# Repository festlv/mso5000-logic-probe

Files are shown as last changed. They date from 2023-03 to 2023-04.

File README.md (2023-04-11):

# MSO5000 logic analyzer probe

This project aims to be a somewhat lower performance but significantly cheaper alternative to Rigol's PLA2216 
logic analyzer probe for MSO5000-series oscilloscopes.

The project is based on the design published by Gandalf_Sr on [EEVBlog forum](https://www.eevblog.com/forum/testgear/ms05000-budget-logic-analyzer-probe-set-design/), 
with the most notable difference being that it should allow input signal threshold selection from the oscilloscope.

The project consists of two PCBs: 

* __connector-pcb__ which plugs into oscilloscope,
* 2x __probe-pcb__'s which connect to the aforementioned PCB via 24-pin IDC cables.

As the original design, it aims to support ~1-5V logic levels up to 100MHz. The probe PCBs can be built with 
two different TI level-shifters:

* SN74AXC8T245 with specified input range of 0.65-3.6V (4.2V abs. max).
* SN74**L**XC8T245 with specified input range of 1.1-5.5V (6.2V abs. max).

Do note that the propagation delay for lower input voltages can limit the observable signal's bandwidth!

## Current status

Revision 0 of both PCBAs has been assembled and passed basic function checks. The only required change was that series resistor
for ProbeDet signal was apparently too high (10K->100R).

Do keep in mind that the threshold level set in scope is not executed faitfhully- it's essentially amplified with a gain of 16.8
and provided as Vcc for SN74AXC8T245. See the datasheet of SN74AXC8T245 and connector-pcb/threshold-vcc-gain-calc.ods spreadsheet for details.

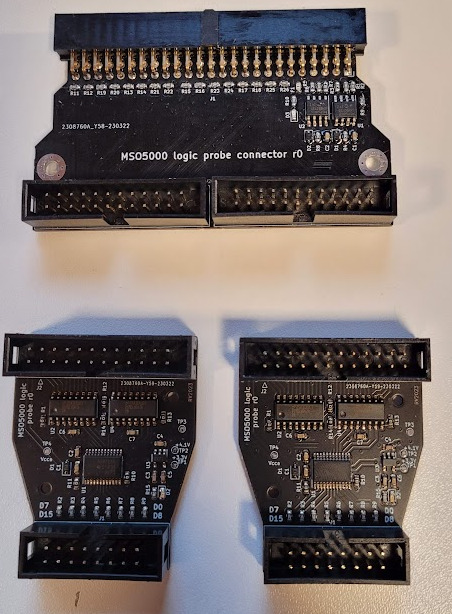
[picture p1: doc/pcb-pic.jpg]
pcb pics


## Connector PCB

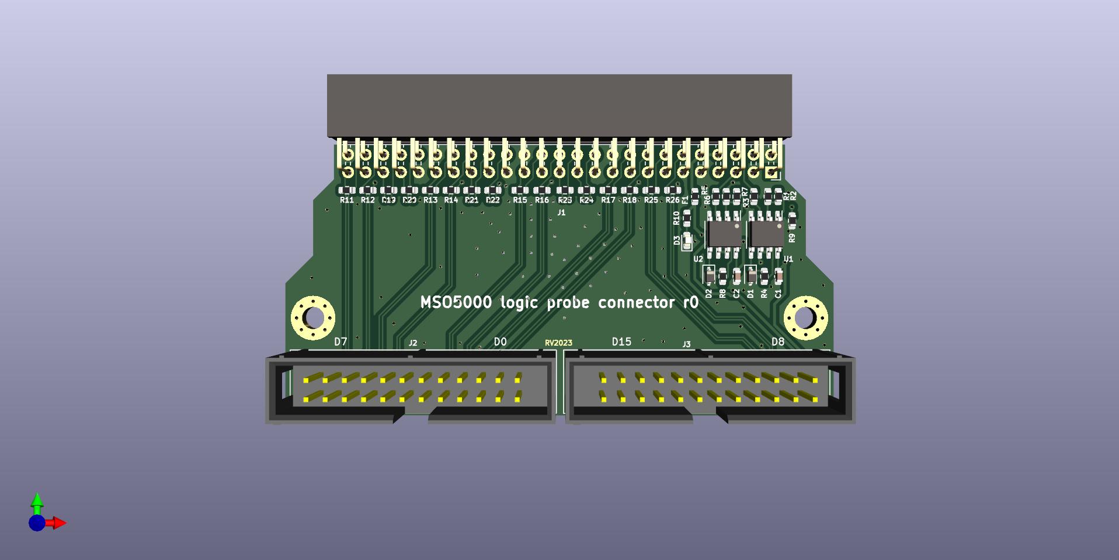
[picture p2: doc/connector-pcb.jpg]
connector pcb


## Probe PCB

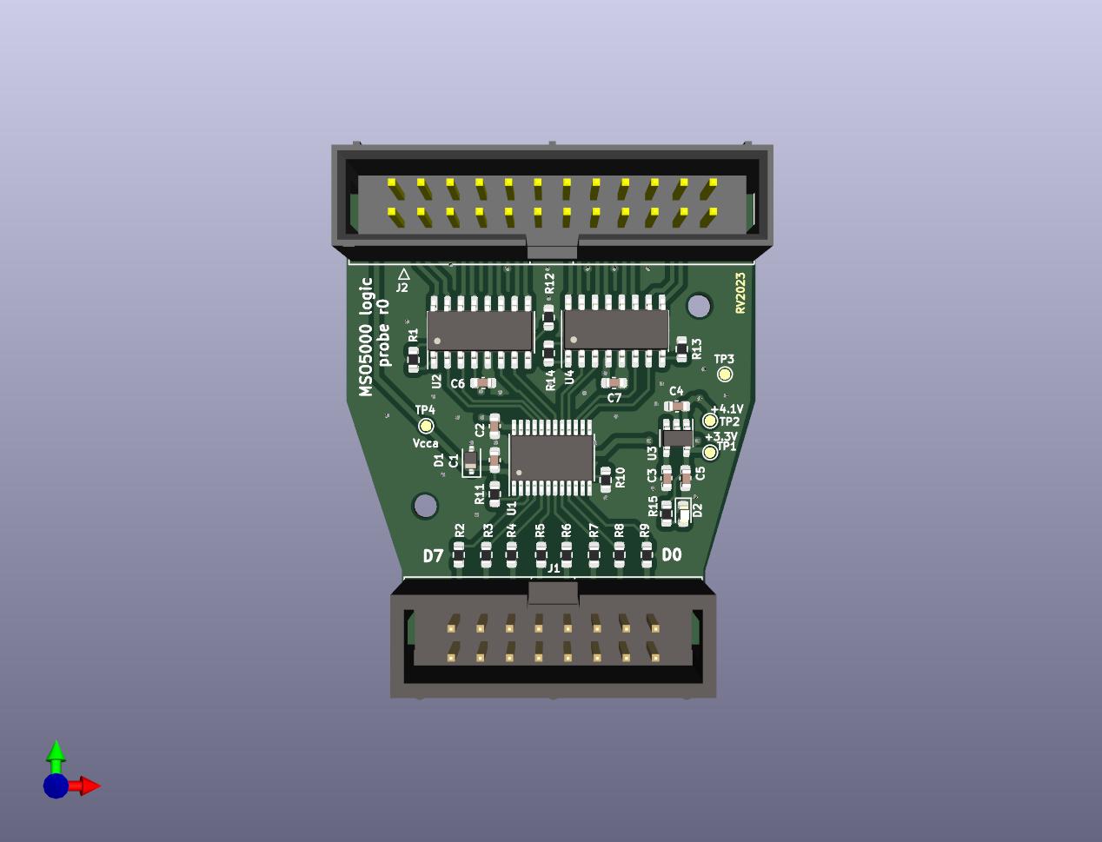
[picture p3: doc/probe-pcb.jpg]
probe pcb


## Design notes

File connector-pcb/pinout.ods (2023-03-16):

ProbeDet | GND | ProbeDet
GND | -2.5Vin | GND
Vref_8-15 | Vref_0-7 | GND
+2.5Vin | +4Vin | -2.5Vin
GND | +4vin | Vref_8-15
GND | D8_N | Vref_0-7
D8_P | D9_p | +2.5Vin
D9_N | D0_N | +4Vin
D0_P | D1_P | GND
D1_N | GND | +4vin
GND | D10_N | GND
D10_P | D11_N | D8_N
DI1_P | D2_N | D8_P
D2_P | D3_P | D9_p
D3_N | GND | D9_N
GND | D12_N | D0_N
D12_P | D13_P | D0_P
D13_N | D4_N | D1_P
D4_P | D5_P | D1_N
D5_N | GND | GND
GND | D14_P | GND
D14_N | D15_P | D10_N
D15_N | D6_N | D10_P
D6_P | D7_P | D11_N
D7_N | GND | DI1_P
 |  | D2_N
 |  | D2_P
 |  | D3_P
 |  | D3_N
 |  | GND
 |  | GND
 |  | D12_N
 |  | D12_P
 |  | D13_P
 |  | D13_N
 |  | D4_N
 |  | D4_P
 |  | D5_P
 |  | D5_N
 |  | GND
 |  | GND
 |  | D14_P
 |  | D14_N
 |  | D15_P
 |  | D15_N
 |  | D6_N
 |  | D6_P
 |  | D7_P
 |  | D7_N
 |  | GND

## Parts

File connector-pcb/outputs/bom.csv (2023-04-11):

Source: | /home/reinis/personal/mso5000-logic/connector-pcb/connector-pcb.kicad_sch
Date: | Tue 11 Apr 2023 07:54:40 PM EEST
Tool: | Eeschema 7.0.1
Generator: | /usr/share/kicad/plugins/bom_csv_grouped_by_value.py
Component Count: | 37
Collated Components:
Item | Qty | Reference(s) | Value | LibPart | Footprint | Datasheet | DNP | LCSC# | MPN | Manufacturer
1 | 2 | C1, C2 | 0.1uF | Device:C_Small | Capacitor_SMD:C_0603_1608Metric | ~ |  | C1591 | CL10B104KB8NNNC | Samsung Electro-Mechanics
2 | 2 | D1, D2 | 3.9V 5% | Device:D_Zener_Small | Diode_SMD:D_SOD-323 | ~ |  | C5359777 | MM3Z3V9 | Fosan
3 | 1 | D3 | LED_GRN | Device:LED_Small | LED_SMD:LED_0603_1608Metric | ~ |  | C965805 | XL-1608SYGC-06 | XINGLIGHT
4 | 1 | F1 | 0.5A | Device:Polyfuse_Small | Fuse:Fuse_0603_1608Metric | ~ |  | C210356 | MF-FSMF020X-2 | BOURNS
5 | 1 | J1 | MSO5000_LA | mso5000:MSO5000_LA | Connector_PinSocket_2.54mm:PinSocket_2x25_P2.54mm_Horizontal | ~ |  |  | SFH11-PBPC-D25-RA-BK | Sullins Connector Solutions
6 | 2 | J2, J3 | IDC_HEADER_2x12 | Connector_Generic:Conn_02x12_Odd_Even | idc:IDC-Header_2x12_P2.54mm_Vertical | ~ |  | C132440 | B-3000S24P-0110 | Ckmtw(Shenzhen Cankemeng)
7 | 3 | R1, R6, R10 | 1K | Device:R_Small | Resistor_SMD:R_0603_1608Metric | ~ |  | C22548 | RC0603FR-071KL | YAGEO
8 | 2 | R2, R7 | 15K8 | Device:R_Small | Resistor_SMD:R_0603_1608Metric | ~ |  | C155689 | RC0603FR-0715K8L | YAGEO
9 | 4 | R3, R4, R5, R8 | 10K | Device:R_Small | Resistor_SMD:R_0603_1608Metric | ~ |  | C98220 | RC0603FR-0710KL | YAGEO
10 | 17 | R9, R11, R12, R13, R14, R15, R16, R17, R18, R19, R20, R21, R22, R23, R24, R25, R26 | 100R | Device:R_Small | Resistor_SMD:R_0603_1608Metric | ~ |  | C105588 | RC0603FR-07100RL | YAGEO
11 | 2 | U1, U2 | MCP6002-xMS | Amplifier_Operational:MCP6002-xMS | Package_SO:SOIC-8_3.9x4.9mm_P1.27mm | http://ww1.microchip.com/downloads/en/DeviceDoc/21733j.pdf |  | C7377 | MCP6002T-I/SN | Microchip

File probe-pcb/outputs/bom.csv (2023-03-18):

Source: | /home/reinis/personal/mso5000-logic/probe-pcb/probe-pcb.kicad_sch
Date: | Sat 18 Mar 2023 02:10:12 AM EET
Tool: | Eeschema 7.0.1
Generator: | /usr/share/kicad/plugins/bom_csv_grouped_by_value.py
Component Count: | 36
Collated Components:
Item | Qty | Reference(s) | Value | LibPart | Footprint | Datasheet | DNP | AltMPN | AltManufacturer | LCSC# | MPN | Manufacturer
1 | 4 | C1, C2, C6, C7 | 0.1uF | Device:C_Small | Capacitor_SMD:C_0603_1608Metric | ~ |  |  |  | C1591 | CL10B104KB8NNNC | Samsung Electro-Mechanics
2 | 1 | C3 | 470pF | Device:C_Small | Capacitor_SMD:C_0603_1608Metric | ~ |  |  |  | C107092 | CC0603KRX7R9BB471 | YAGEO
3 | 2 | C4, C5 | 2.2uF | Device:C_Small | Capacitor_SMD:C_0603_1608Metric | ~ |  |  |  | C1607 | CL10A225KP8NNNC | Samsung Electro-Mechanics
4 | 1 | D1 | 3.9V 5% | Device:D_Zener_Small | Diode_SMD:D_SOD-323 | ~ |  |  |  | C5359777 | MM3Z3V9 | Fosan
5 | 1 | D2 | LED_GRN | Device:LED_Small | LED_SMD:LED_0603_1608Metric | ~ |  |  |  | C965805 | XL-1608SYGC-06 | XINGLIGHT
6 | 2 | H1, H2 | MountingHole | Mechanical:MountingHole | MountingHole:MountingHole_2.2mm_M2 | ~
7 | 1 | J1 | IDC_HEADER_02x08 | Connector_Generic:Conn_02x08_Odd_Even | Connector_IDC:IDC-Header_2x08_P2.54mm_Vertical | ~ |  |  |  | C132430 | B-3000S16P-0110 | Ckmtw(Shenzhen Cankemeng)
8 | 1 | J2 | IDC_HEADER_2x12 | Connector_Generic:Conn_02x12_Odd_Even | idc:IDC-Header_2x12_P2.54mm_Vertical | ~ |  |  |  | C132440 | B-3000S24P-0110 | Ckmtw(Shenzhen Cankemeng)
9 | 6 | R1, R10, R11, R12, R13, R14 | 0R | Device:R_Small | Resistor_SMD:R_0603_1608Metric | ~ |  |  |  | C95177 | RC0603JR-070RL | YAGEO
10 | 8 | R2, R3, R4, R5, R6, R7, R8, R9 | 100R | Device:R_Small | Resistor_SMD:R_0603_1608Metric | ~ |  |  |  | C105588 | RC0603FR-07100RL | YAGEO
11 | 1 | R15 | 1K | Device:R_Small | Resistor_SMD:R_0603_1608Metric | ~ |  |  |  | C22548 | RC0603FR-071KL | YAGEO
12 | 4 | TP1, TP2, TP3, TP4 | TP_1MM | Connector:TestPoint | TestPoint:TestPoint_Pad_D1.0mm | ~
13 | 1 | U1 | SN74AXC8T245 | mso5000:SN74AXC8T245 | Package_SO:TSSOP-24_4.4x7.8mm_P0.65mm | https://www.ti.com/lit/ds/symlink/sn74axc8t245.pdf?ts=1678888996176 |  | SN74LXC8T245QPWRQ1 |  | C882718 | SN74AXC8T245PWR | TI
14 | 2 | U2, U4 | DS90LV047A | mso5000:DS90LV047A | Package_SO:SOIC-16_3.9x9.9mm_P1.27mm | http://www.ti.com/lit/ds/symlink/ds90lv027a.pdf |  |  |  | C206491 | DS90LV047ATMX/NOPB | TI
15 | 1 | U3 | MIC5205-3.3YM5 | Regulator_Linear:MIC5205-3.3YM5 | Package_TO_SOT_SMD:SOT-23-5 | http://ww1.microchip.com/downloads/en/DeviceDoc/20005785A.pdf |  | TJ5205SF5-3.3 | HTC Korea TAEJIN Tech | C126090 | MIC5205-3.3YM5-TR | Microchip

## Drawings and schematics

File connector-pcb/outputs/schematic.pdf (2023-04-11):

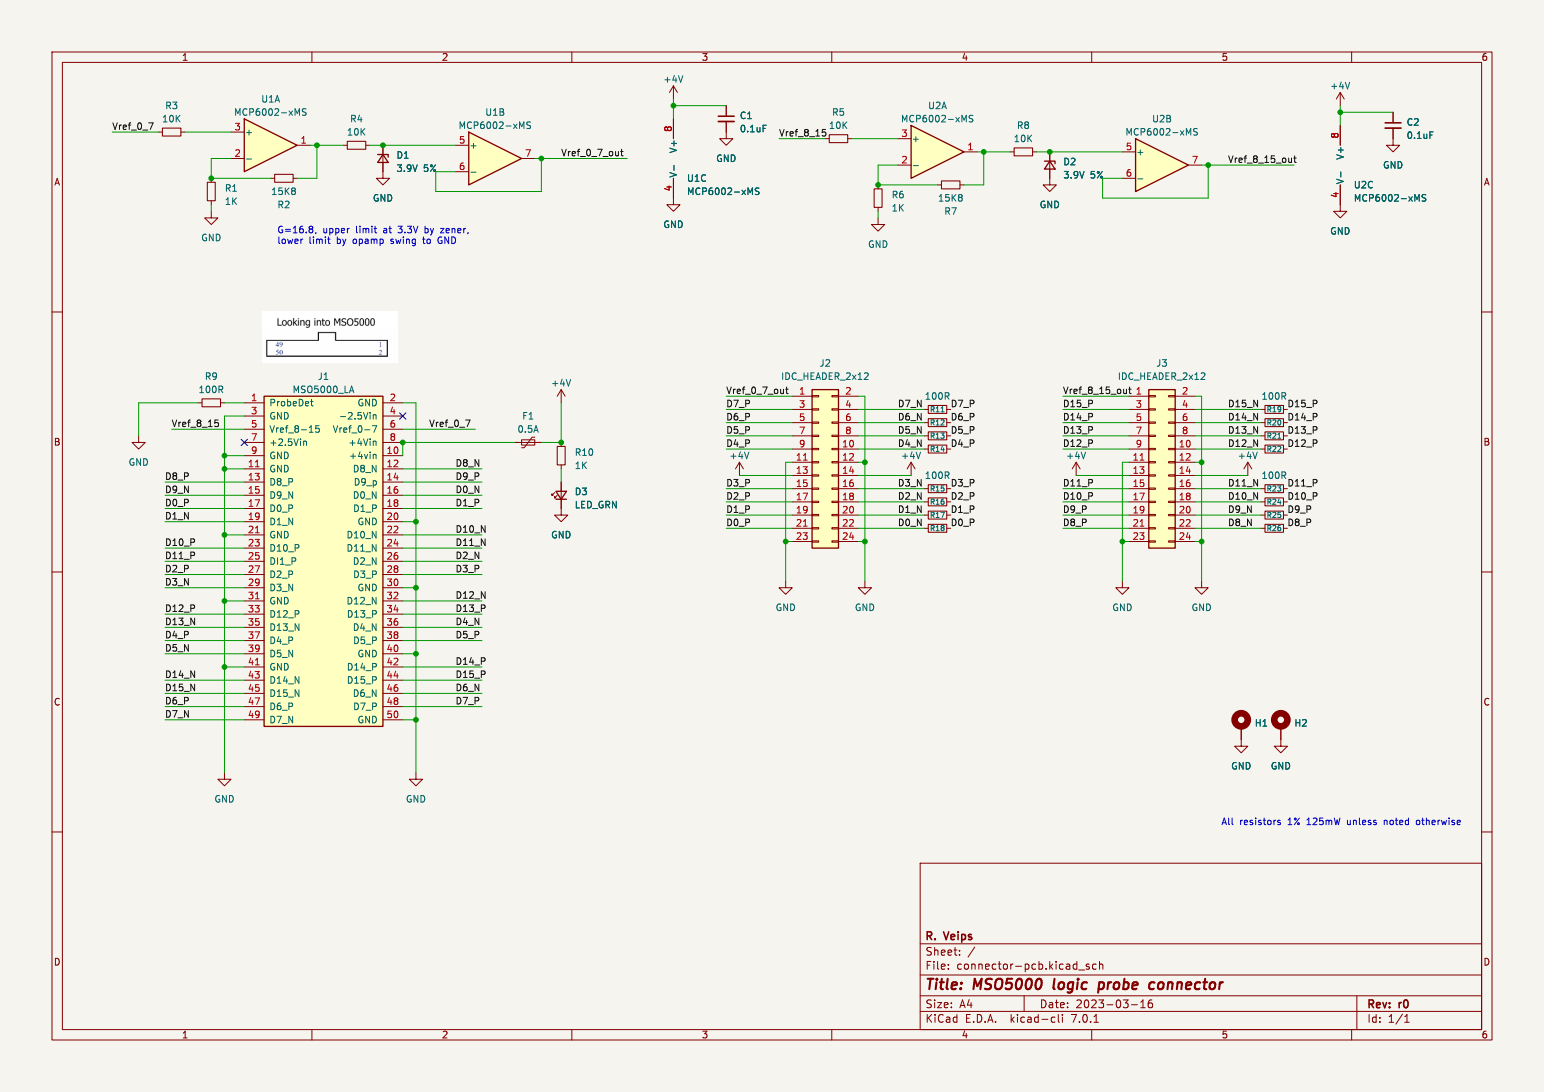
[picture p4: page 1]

G=16.8, upper limit at 3.3V by zener,

Id: 1/1 Title: MSO5000 logic probe connector File: connector-pcb.kicad_sch Sheet: / R. Veips

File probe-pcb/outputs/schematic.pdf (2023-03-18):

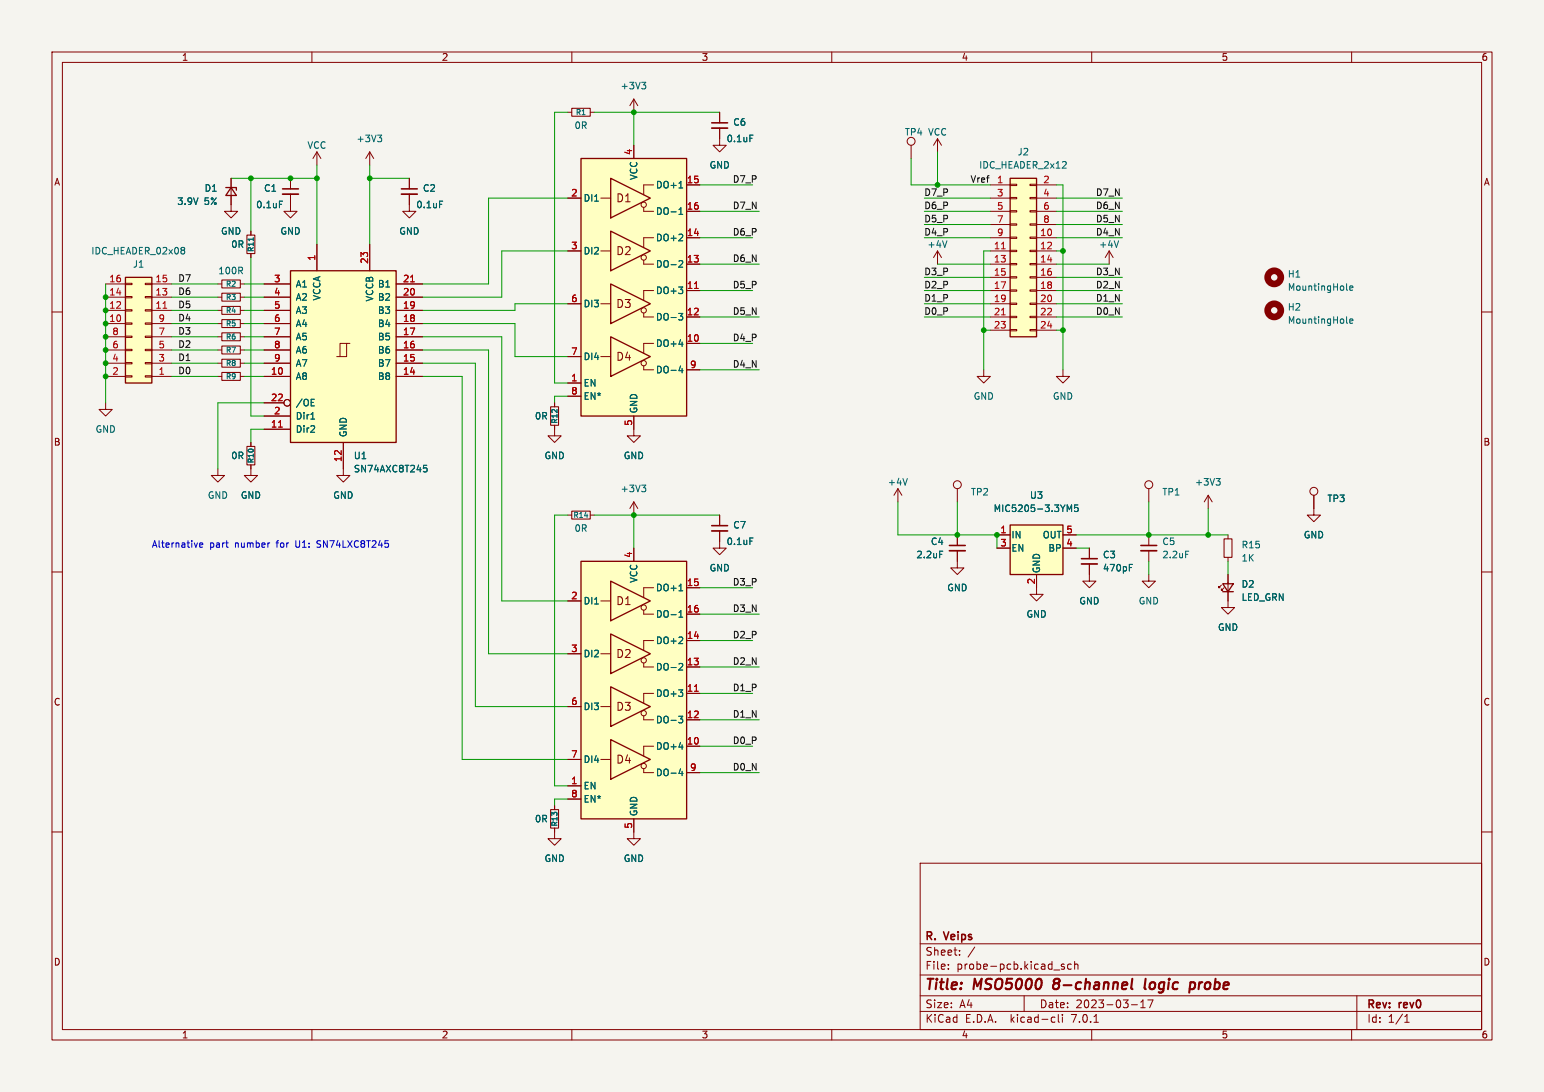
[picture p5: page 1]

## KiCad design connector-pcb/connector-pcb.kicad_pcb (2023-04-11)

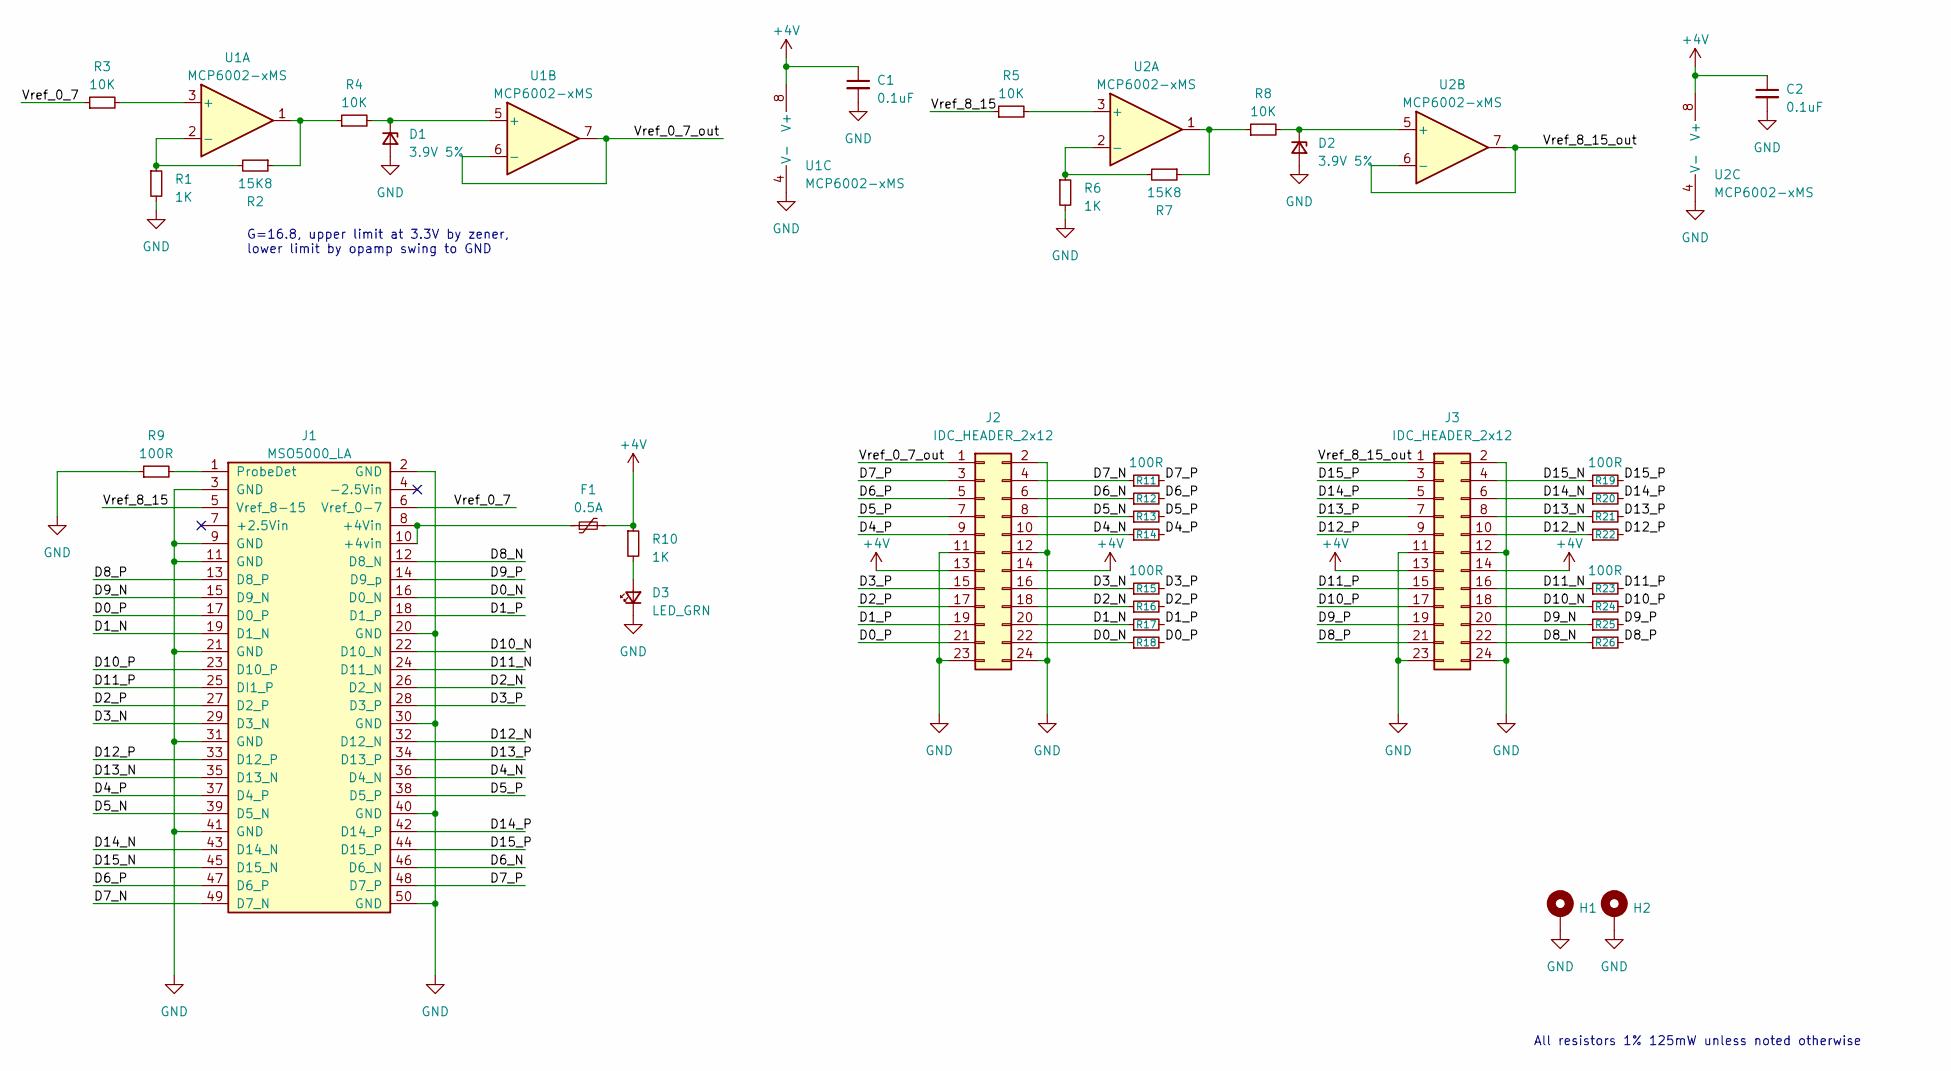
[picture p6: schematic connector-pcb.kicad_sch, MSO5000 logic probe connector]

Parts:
C1, C2: 0.1uF; C_0603_1608Metric; MPN CL10B104KB8NNNC; LCSC# C1591
D1, D2: 3.9V 5%; D_SOD-323; MPN MM3Z3V9; LCSC# C5359777
D3: LED_GRN; LED_0603_1608Metric; MPN XL-1608SYGC-06; LCSC# C965805
F1: 0.5A; Fuse_0603_1608Metric; MPN MF-FSMF020X-2; LCSC# C210356
H1, H2: MountingHole_Pad; MountingHole_3.2mm_M3_Pad_Via
J1: MSO5000_LA; PinSocket_2x25_P2.54mm_Horizontal; MPN SFH11-PBPC-D25-RA-BK
J2, J3: IDC_HEADER_2x12; IDC-Header_2x12_P2.54mm_Vertical; MPN B-3000S24P-0110; LCSC# C132440
R1, R6, R10: 1K; R_0603_1608Metric; MPN RC0603FR-071KL; LCSC# C22548
R2, R7: 15K8; R_0603_1608Metric; MPN RC0603FR-0715K8L; LCSC# C155689
R3, R4, R5, R8: 10K; R_0603_1608Metric; MPN RC0603FR-0710KL; LCSC# C98220
R9, R11, R12, R13, R14, R15, R16, R17, R18, R19, R20, R21, R22, R23, R24, R25, R26: 100R; R_0603_1608Metric; MPN RC0603FR-07100RL; LCSC# C105588
U1, U2: MCP6002-xMS; SOIC-8_3.9x4.9mm_P1.27mm; MPN MCP6002T-I/SN; LCSC# C7377

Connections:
+4V: C1.1, C2.1, F1.2, J2.13, J2.14, J3.13, J3.14, R10.1, U1.8 (V+), U2.8 (V+)
/D0_N: J1.16 (D0_N), J2.22, R18.1
/D0_P: J1.17 (D0_P), J2.21, R18.2
/D1_N: J1.19 (D1_N), J2.20, R17.1
/D1_P: J1.18 (D1_P), J2.19, R17.2
/D2_N: J1.26 (D2_N), J2.18, R16.1
/D2_P: J1.27 (D2_P), J2.17, R16.2
/D3_N: J1.29 (D3_N), J2.16, R15.1
/D3_P: J1.28 (D3_P), J2.15, R15.2
/D4_N: J1.36 (D4_N), J2.10, R14.1
/D4_P: J1.37 (D4_P), J2.9, R14.2
/D5_N: J1.39 (D5_N), J2.8, R13.1
/D5_P: J1.38 (D5_P), J2.7, R13.2
/D6_N: J1.46 (D6_N), J2.6, R12.1
/D6_P: J1.47 (D6_P), J2.5, R12.2
/D7_N: J1.49 (D7_N), J2.4, R11.1
/D7_P: J1.48 (D7_P), J2.3, R11.2
/D8_N: J1.12 (D8_N), J3.22, R26.1
/D8_P: J1.13 (D8_P), J3.21, R26.2
/D9_N: J1.15 (D9_N), J3.20, R25.1
/D9_P: J1.14 (D9_p), J3.19, R25.2
/D10_N: J1.22 (D10_N), J3.18, R24.1
/D10_P: J1.23 (D10_P), J3.17, R24.2
/D11_N: J1.24 (D11_N), J3.16, R23.1
/D11_P: J1.25 (DI1_P), J3.15, R23.2
/D12_N: J1.32 (D12_N), J3.10, R22.1
/D12_P: J1.33 (D12_P), J3.9, R22.2
/D13_N: J1.35 (D13_N), J3.8, R21.1
/D13_P: J1.34 (D13_P), J3.7, R21.2
/D14_N: J1.43 (D14_N), J3.6, R20.1
/D14_P: J1.42 (D14_P), J3.5, R20.2
/D15_N: J1.45 (D15_N), J3.4, R19.1
/D15_P: J1.44 (D15_P), J3.3, R19.2
/Vref_0_7: J1.6 (Vref_0-7), R3.1
/Vref_0_7_out: J2.1, U1.6 (-), U1.7
/Vref_8_15: J1.5 (Vref_8-15), R5.1
/Vref_8_15_out: J3.1, U2.6 (-), U2.7
GND: C1.2, C2.2, D1.2 (A), D2.2 (A), D3.1 (K), H1.1, H2.1, J1.2 (GND), J1.3 (GND), J1.9 (GND), J1.11 (GND), J1.20 (GND), J1.21 (GND), J1.30 (GND), J1.31 (GND), J1.40 (GND), J1.41 (GND), J1.50 (GND), J2.2, J2.11, J2.12, J2.23, J2.24, J3.2, J3.11, J3.12, J3.23, J3.24, R1.2, R6.2, R9.1, U1.4 (V-), U2.4 (V-)
unnamed: D1.1 (K), R4.2, U1.5 (+)
unnamed: D2.1 (K), R8.2, U2.5 (+)
unnamed: D3.2 (A), R10.2
unnamed: F1.1, J1.8 (+4Vin), J1.10 (+4vin)
unnamed: J1.1 (ProbeDet), R9.2
unnamed: R2.1, R4.1, U1.1
unnamed: R7.1, R8.1, U2.1
unnamed: R3.2, U1.3 (+)
unnamed: R1.1, R2.2, U1.2 (-)
unnamed: R5.2, U2.3 (+)
unnamed: R6.1, R7.2, U2.2 (-)

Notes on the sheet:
G=16.8, upper limit at 3.3V by zener, lower limit by opamp swing to GND
All resistors 1% 125mW unless noted otherwise

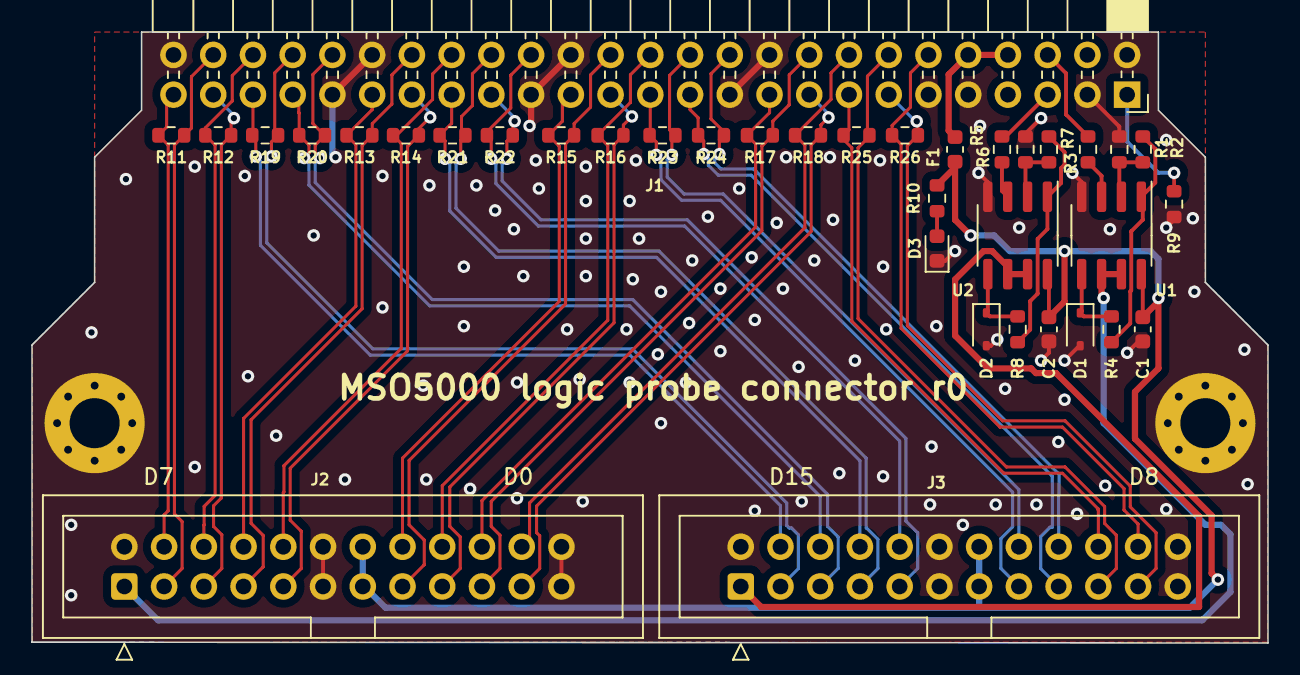
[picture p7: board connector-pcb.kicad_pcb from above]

Board: 4 copper layers, 79.0 x 39.0 mm, 39 parts (0 on the bottom side), 49 nets.

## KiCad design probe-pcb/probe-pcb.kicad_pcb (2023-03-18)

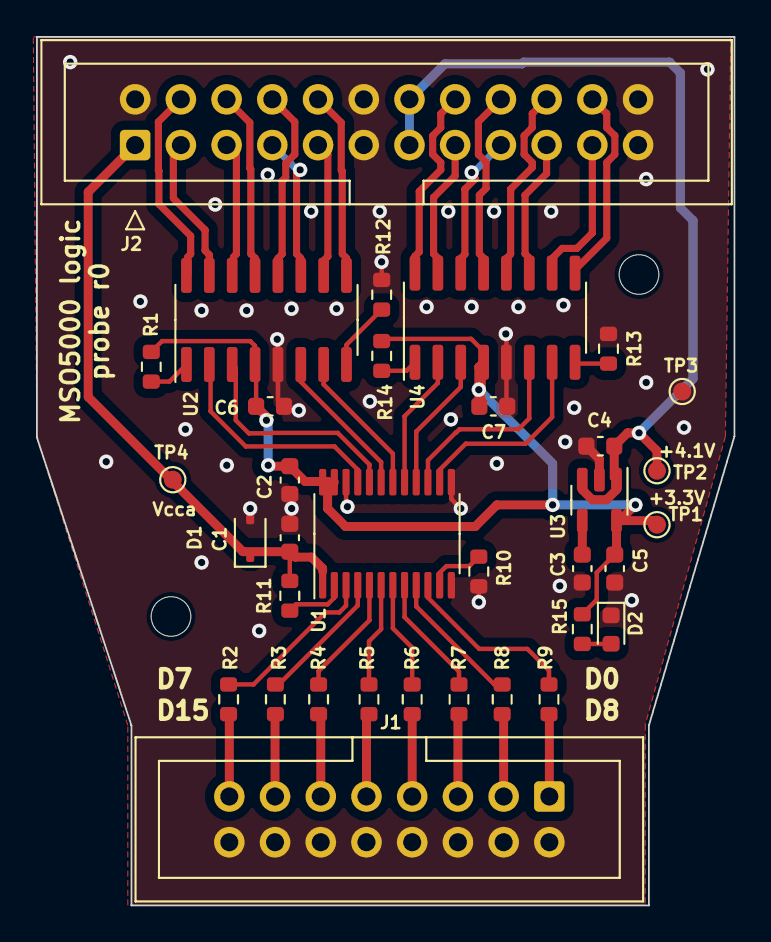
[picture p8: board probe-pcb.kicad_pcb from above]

Board: 2 copper layers, 38.8 x 48.2 mm, 36 parts (0 on the bottom side), 52 nets.

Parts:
C1, C2, C6, C7: 0.1uF; C_0603_1608Metric
C3: 470pF; C_0603_1608Metric
C4, C5: 2.2uF; C_0603_1608Metric
D1: 3.9V 5%; D_SOD-323
D2: LED_GRN; LED_0603_1608Metric
H1, H2: MountingHole; MountingHole_2.2mm_M2
J1: IDC_HEADER_02x08; IDC-Header_2x08_P2.54mm_Vertical
J2: IDC_HEADER_2x12; IDC-Header_2x12_P2.54mm_Vertical
R1, R10, R11, R12, R13, R14: 0R; R_0603_1608Metric
R2, R3, R4, R5, R6, R7, R8, R9: 100R; R_0603_1608Metric
R15: 1K; R_0603_1608Metric
TP1, TP2, TP3, TP4: TP_1MM; TestPoint_Pad_D1.0mm
U1: SN74AXC8T245; TSSOP-24_4.4x7.8mm_P0.65mm
U2, U4: DS90LV047A; SOIC-16_3.9x9.9mm_P1.27mm
U3: MIC5205-3.3YM5; SOT-23-5

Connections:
+3V3: C2.1, C5.1, C6.1, C7.1, R1.1, R14.1, R15.1, TP1.1, U1.23 (VCCB), U1.24 (VCCB), U2.4 (VCC), U3.5 (OUT), U4.4 (VCC)
+4V: C4.1, J2.13, J2.14, TP2.1, U3.1 (IN), U3.3 (EN)
/D0: J1.1, R9.1
/D0_N: J2.22, U4.9 (DO-4)
/D0_P: J2.21, U4.10 (DO+4)
/D1: J1.3, R8.1
/D1_N: J2.20, U4.12 (DO-3)
/D1_P: J2.19, U4.11 (DO+3)
/D2: J1.5, R7.1
/D2_N: J2.18, U4.13 (DO-2)
/D2_P: J2.17, U4.14 (DO+2)
/D3: J1.7, R6.1
/D3_N: J2.16, U4.16 (DO-1)
/D3_P: J2.15, U4.15 (DO+1)
/D4: J1.9, R5.1
/D4_N: J2.10, U2.9 (DO-4)
/D4_P: J2.9, U2.10 (DO+4)
/D5: J1.11, R4.1
/D5_N: J2.8, U2.12 (DO-3)
/D5_P: J2.7, U2.11 (DO+3)
/D6: J1.13, R3.1
/D6_N: J2.6, U2.13 (DO-2)
/D6_P: J2.5, U2.14 (DO+2)
/D7: J1.15, R2.1
/D7_N: J2.4, U2.16 (DO-1)
/D7_P: J2.3, U2.15 (DO+1)
GND: C1.2, C2.2, C3.2, C4.2, C5.2, C6.2, C7.2, D1.2 (A), D2.1 (K), J1.2, J1.4, J1.6, J1.8, J1.10, J1.12, J1.14, J1.16, J2.2, J2.11, J2.12, J2.23, J2.24, R10.1, R12.1, R13.1, TP3.1, U1.12 (GND), U1.13 (GND), U1.22 (/OE), U2.5 (GND), U3.2 (GND), U4.5 (GND)
unnamed: D2.2 (A), R15.2
unnamed: R2.2, U1.3 (A1)
unnamed: R3.2, U1.4 (A2)
unnamed: R4.2, U1.5 (A3)
unnamed: R5.2, U1.6 (A4)
unnamed: R6.2, U1.7 (A5)
unnamed: R7.2, U1.8 (A6)
unnamed: R8.2, U1.9 (A7)
unnamed: R9.2, U1.10 (A8)
unnamed: U1.21 (B1), U2.2 (DI1)
unnamed: U1.20 (B2), U2.3 (DI2)
unnamed: U1.19 (B3), U2.6 (DI3)
unnamed: U1.18 (B4), U2.7 (DI4)
unnamed: U1.17 (B5), U4.2 (DI1)
unnamed: U1.16 (B6), U4.3 (DI2)
unnamed: U1.15 (B7), U4.6 (DI3)
unnamed: U1.14 (B8), U4.7 (DI4)
unnamed: R11.1, U1.2 (Dir1)
unnamed: R10.2, U1.11 (Dir2)
unnamed: R1.2, U2.1 (EN)
unnamed: R12.2, U2.8 (EN*)
unnamed: C3.1, U3.4 (BP)
unnamed: R14.2, U4.1 (EN)
unnamed: R13.2, U4.8 (EN*)
VCC: C1.1, D1.1 (K), J2.1, R11.2, TP4.1, U1.1 (VCCA)

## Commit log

2023-03-16 Add r0 of connector PCB
    [bom.csv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]
2023-03-17 Change connector PCB to 4 layer board, finalize probe board
    [bom.csv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]
2023-03-17 Add 3d model for 2x12 pin header (missing in kicad library), add readme
    [connector-pcb.kicad_pcb, connector-pcb.kicad_sch, probe-pcb.kicad_pcb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]
2023-03-18 Change zener diodes to 3.9V (should protect both 3.3V and 5V level shifters)
    [bom.csv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]
2023-04-11 Changed R9 of connector PCB from 10k to 100R (otherwise the scope wouldn't detect the probes)
    [bom.csv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]
2023-04-11 Update readme with status of testing and pics of assembled boards
